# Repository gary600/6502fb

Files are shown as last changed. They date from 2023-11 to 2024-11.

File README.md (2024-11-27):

# 6502 Framebuffer
A 160 by 120 pixel, 256-color framebuffer and VGA generator for a 6502-based computer, made
for CMU 98-341 Build Your Own Breadboard Computer.

Heavily inspired by Ben Eater's "[world's worst video
card](https://www.youtube.com/watch?v=l7rce6IQDWs)" saga, but with many
improvements:
- better timing compliance (shorter critical path -> no vertical artifacts)
- FFs instead of latches (easier to debug timing)
- higher resolution (160x120 vs. 100x75), accomplished through memory banking
- more common VGA mode (640x480 vs. 800x600)
- double-bufferring (updates aren't restricted to blanking period)
- software blanking (show solid black or white without drawing to every pixel)
- configurability (disable NMI if not needed)

This repo contains the KiCad files for the board, a corresponding Verilog
design and testbench, and a software simulator.

The board went through 2 revisions before it worked fully:

## Rev1
Revision 1 worked well enough to generate a valid VGA signal, but I made a major
mistake on the SRAM pinout which led to it not being able to interface with the
6502 computer. Another mistake: my minimum via diameter was too small, so it
cost like $40 extra...

However, despite these faults, I was able to bodge the row and column pins to
allow it to display an image from an EEPROM.

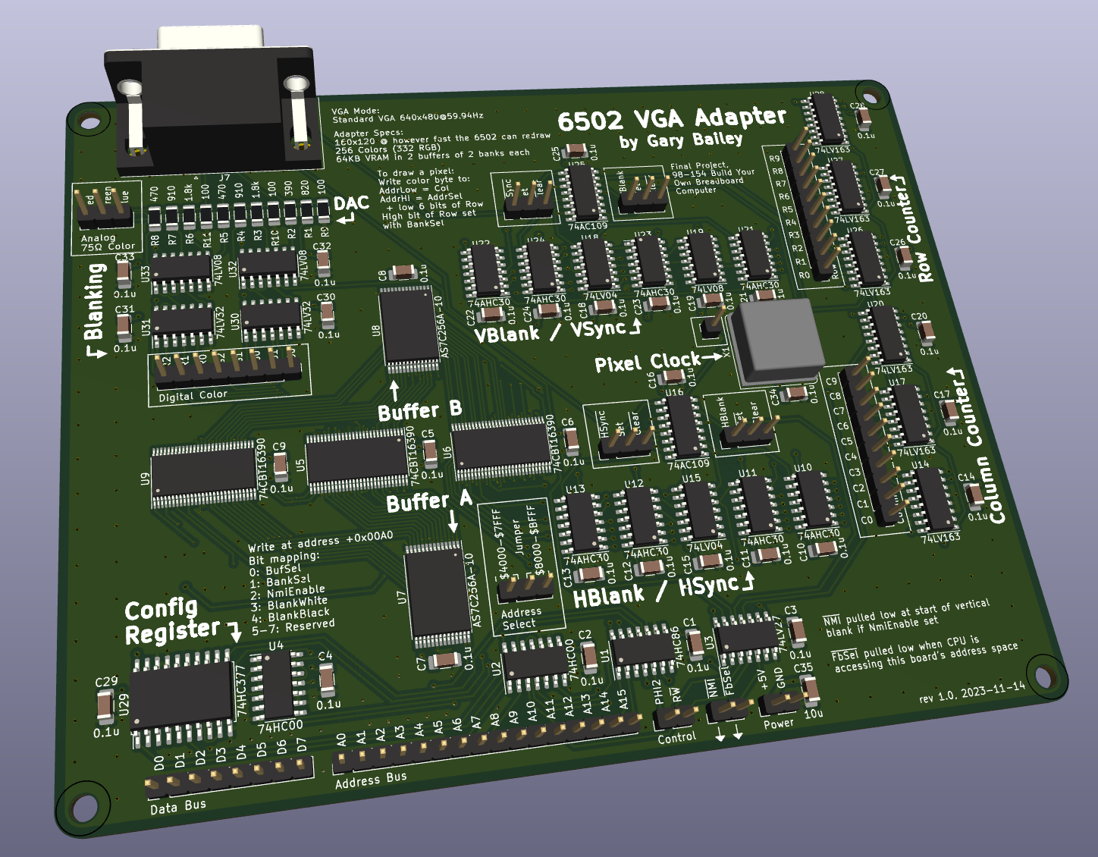
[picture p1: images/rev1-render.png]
KiCad render

KiCad render

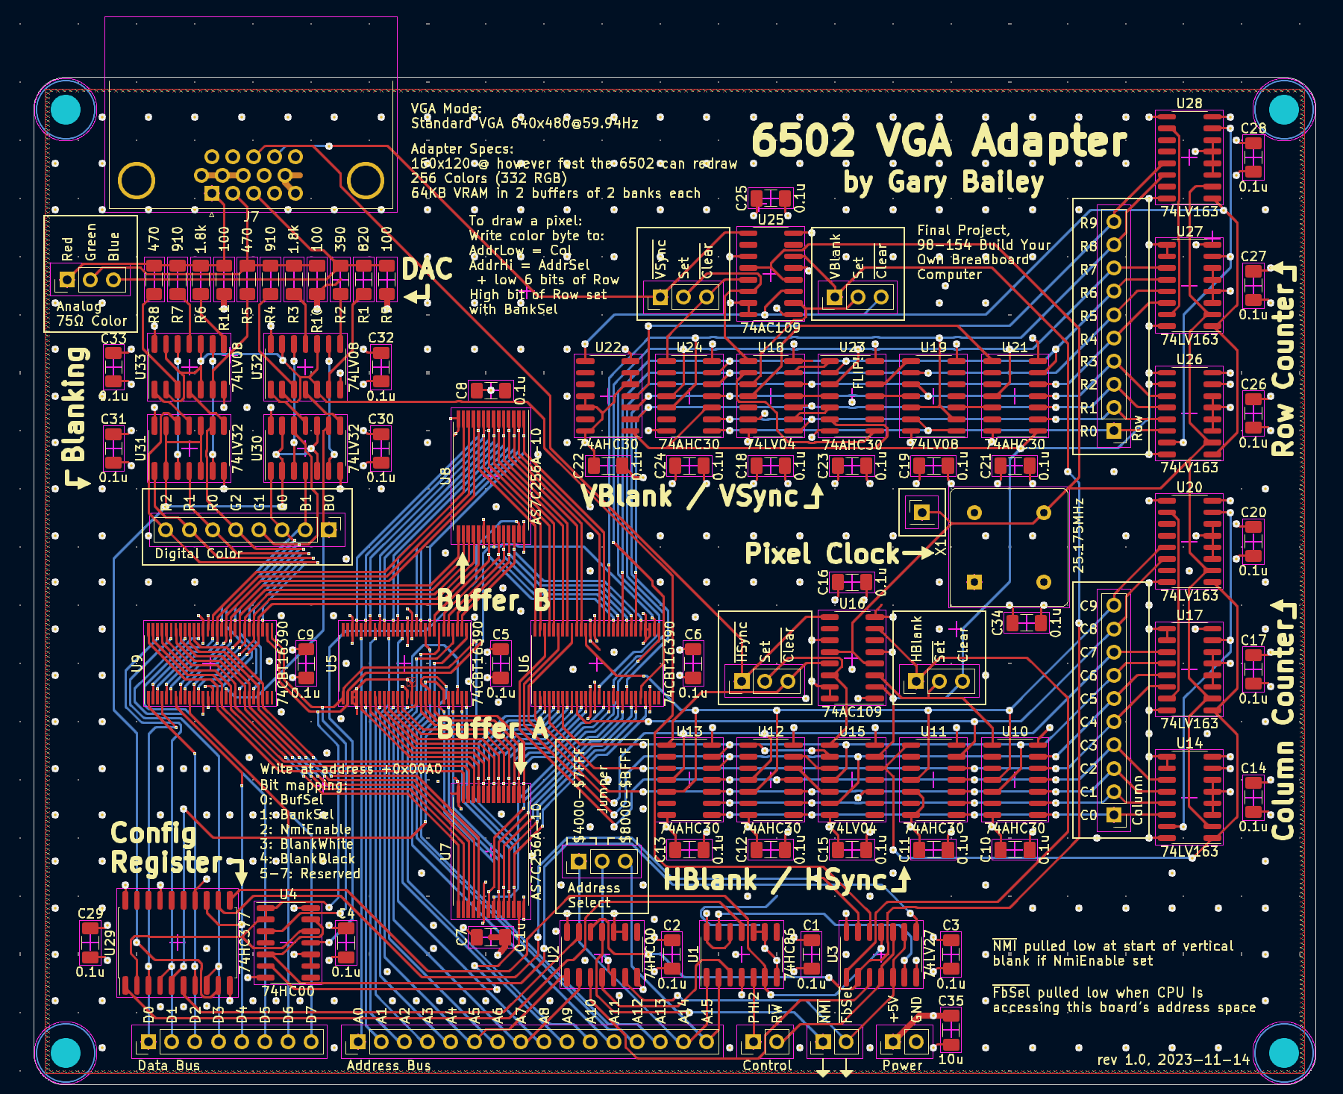
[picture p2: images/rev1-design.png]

KiCad board view

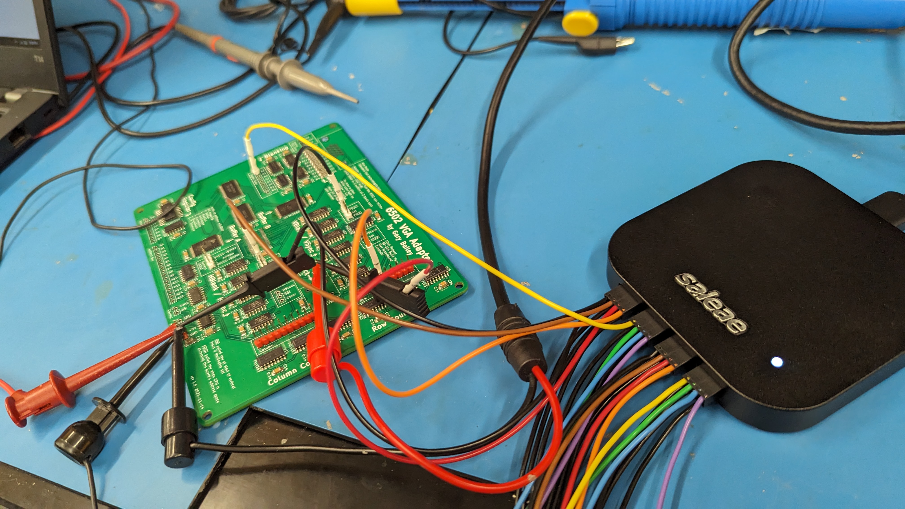
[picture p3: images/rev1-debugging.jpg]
Debugging...
 Part of the arduous debugging
process that eventually led to me discovering the SRAM mistake...

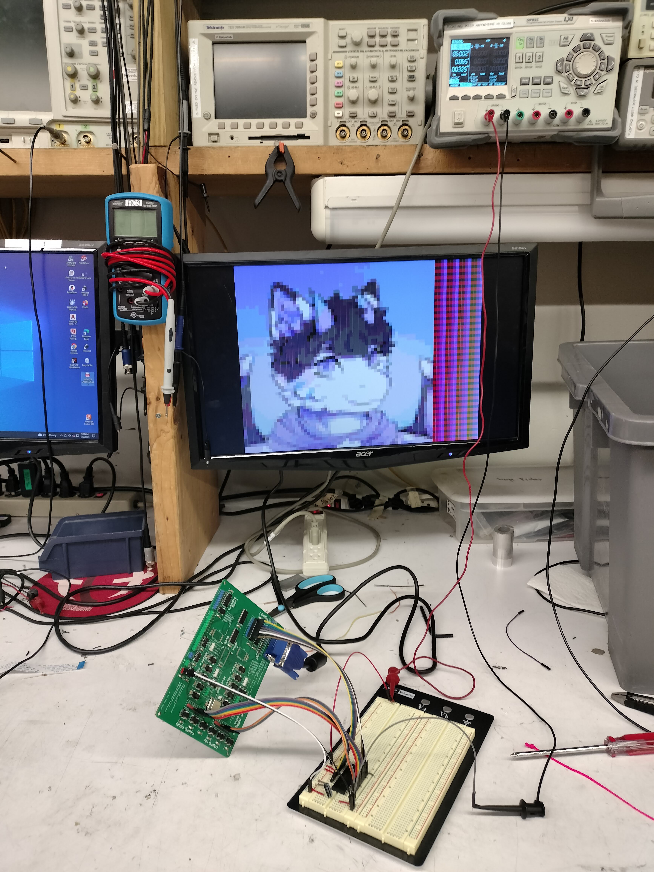
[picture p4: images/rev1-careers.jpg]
It works!
 It works! (with a static image...) The
EEPROM I used here has a much slower read speed than the SRAMs I designed for,
which leads to the vertial artifacts on some pixels here.

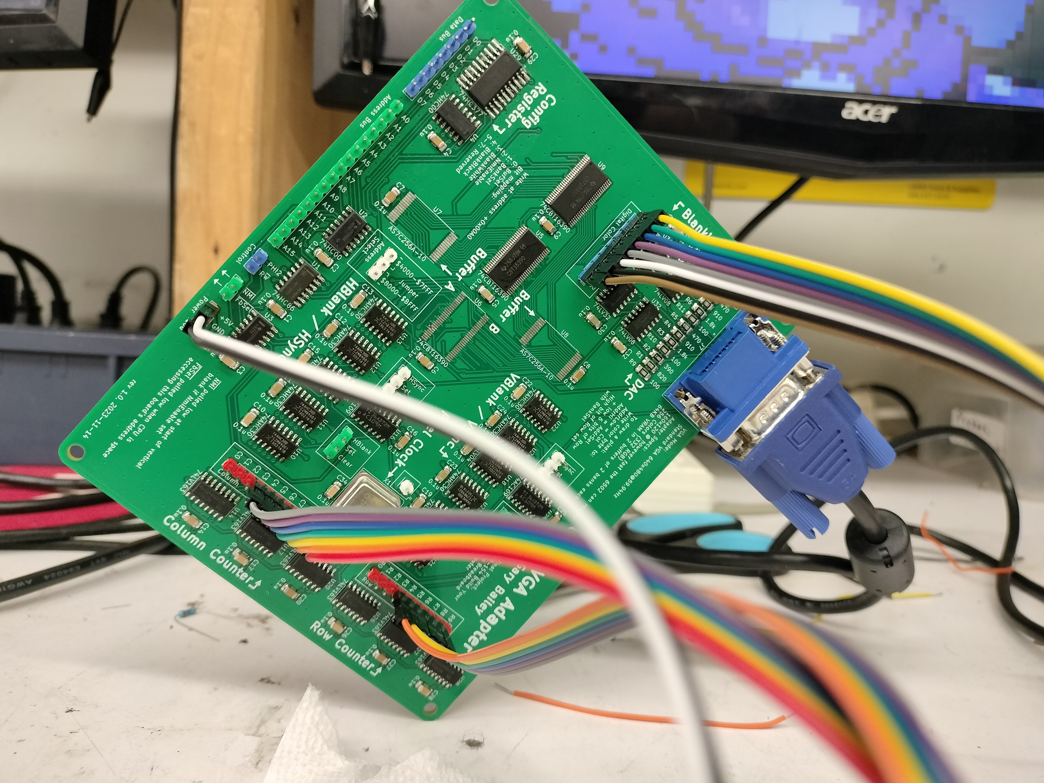
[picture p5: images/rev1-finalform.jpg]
Final form

Closeup of Rev1 bodges: SRAMs removed and row/column signals routed to EEPROM + color routed in through header

## Rev2
Revision 2 fixed the pinout of the SRAM ICs, fixed the via size issue, added a
debug header for the config register, and added an optional 5V regulator that
can be used to power the entire computer.

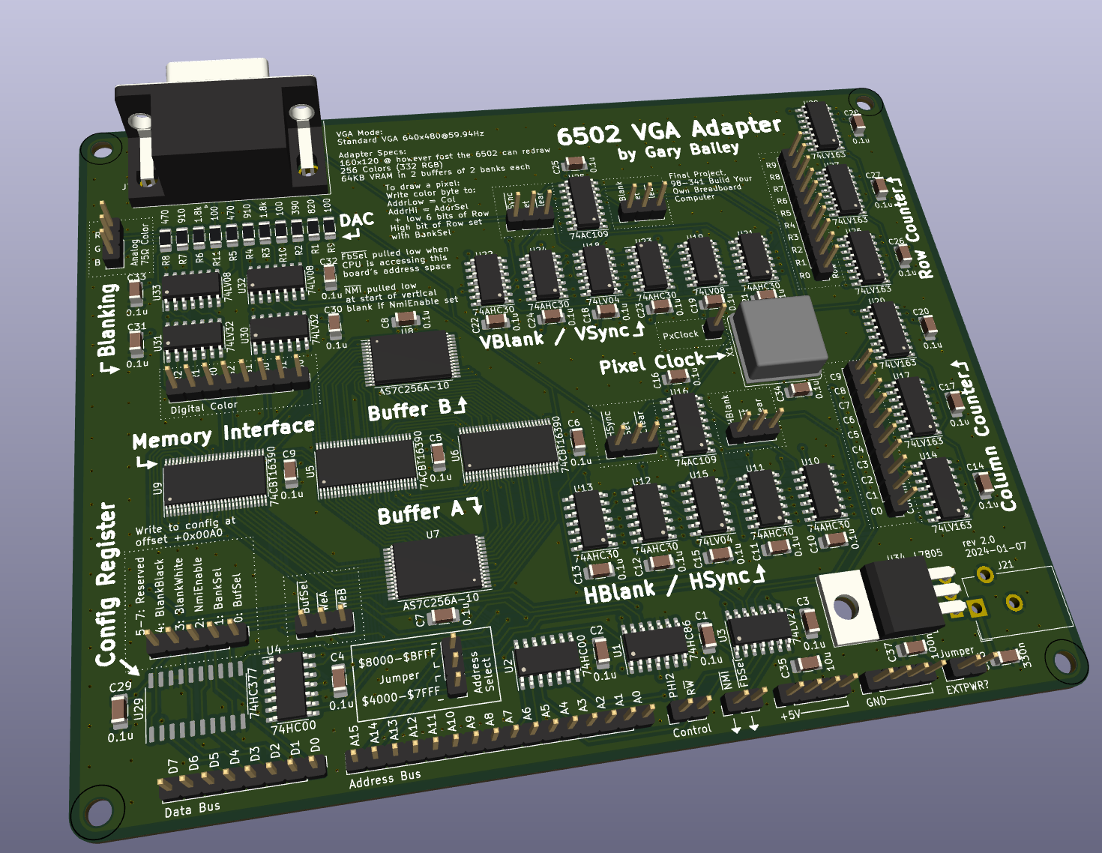
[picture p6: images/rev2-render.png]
KiCad render

KiCad render

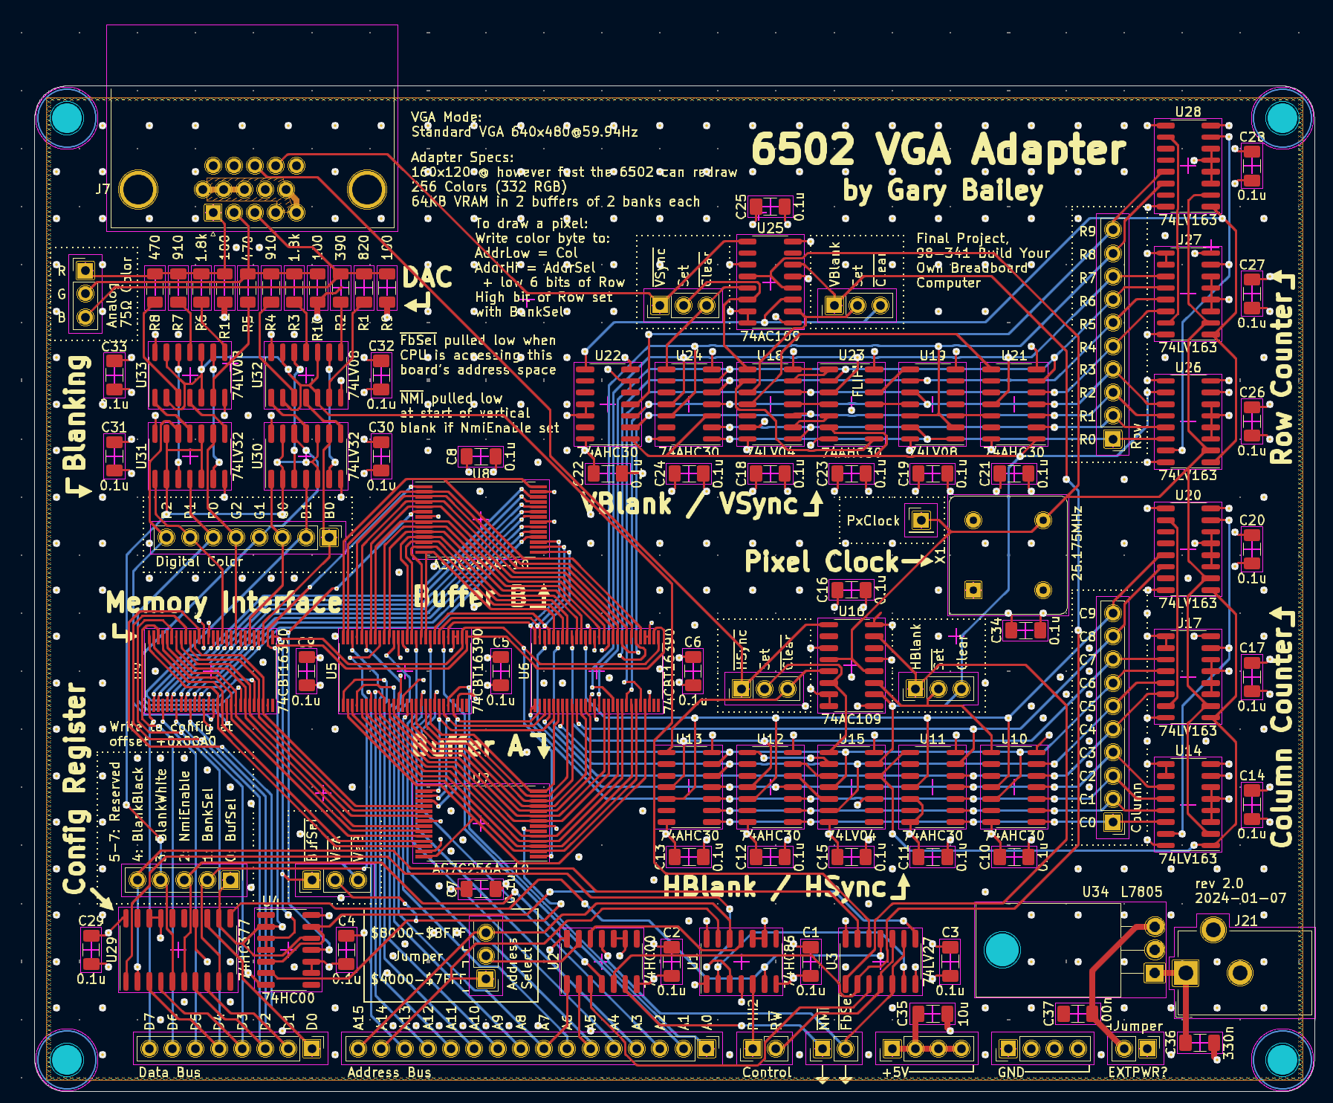
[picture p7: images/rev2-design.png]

KiCad board view

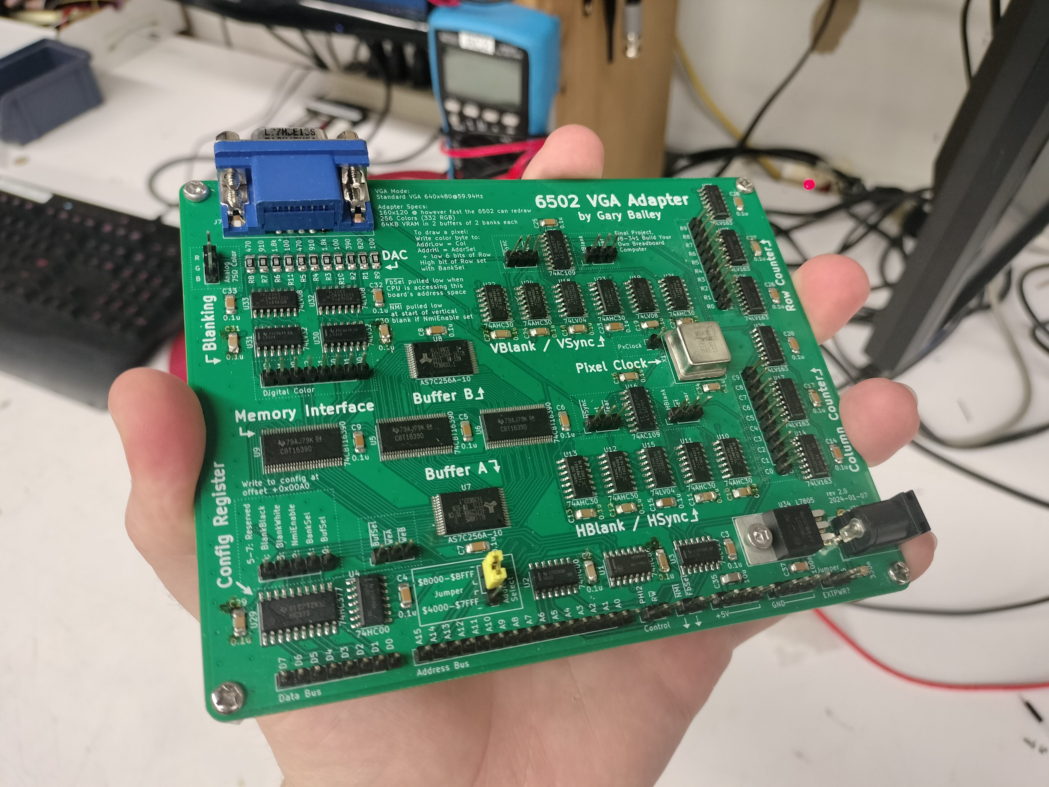
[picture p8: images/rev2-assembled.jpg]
Final assembled board

Final assembled board!

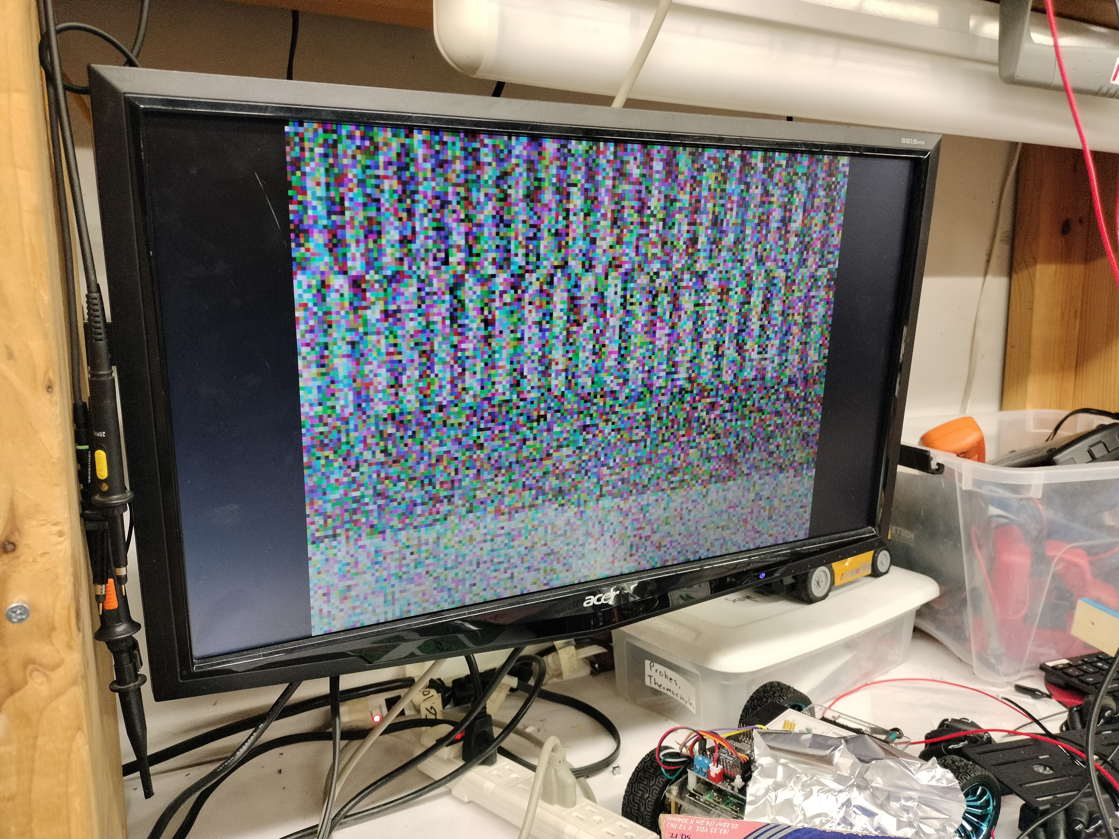
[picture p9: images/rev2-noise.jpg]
Power-on noise

Power-on noise: this is expected! The SRAM does not have a deterministic state when powered on.

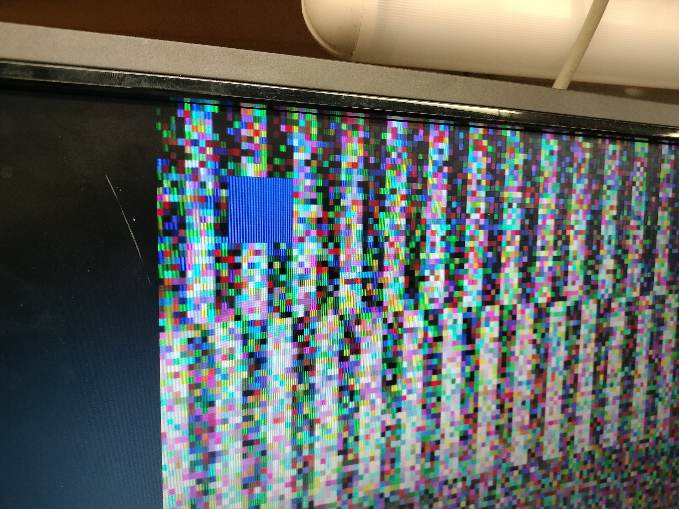
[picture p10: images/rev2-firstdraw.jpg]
Drawing works

Drawing to the screen works!

Moving image
And it can redraw live!

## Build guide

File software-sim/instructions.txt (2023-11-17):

ADC  Add Memory to Accumulator with Carry

     A + M + C -> A, C                N Z C I D V
                                      + + + - - +

     addressing    assembler    opc  bytes  cyles
     --------------------------------------------
     immediate     ADC #oper     69    2     2
     zeropage      ADC oper      65    2     3
     zeropage,X    ADC oper,X    75    2     4
     absolute      ADC oper      6D    3     4
     absolute,X    ADC oper,X    7D    3     4*
     absolute,Y    ADC oper,Y    79    3     4*
     (indirect,X)  ADC (oper,X)  61    2     6
     (indirect),Y  ADC (oper),Y  71    2     5*

AND  AND Memory with Accumulator

     A AND M -> A                     N Z C I D V
                                      + + - - - -

     addressing    assembler    opc  bytes  cyles
     --------------------------------------------
     immediate     AND #oper     29    2     2
     zeropage      AND oper      25    2     3
     zeropage,X    AND oper,X    35    2     4
     absolute      AND oper      2D    3     4
     absolute,X    AND oper,X    3D    3     4*
     absolute,Y    AND oper,Y    39    3     4*
     (indirect,X)  AND (oper,X)  21    2     6
     (indirect),Y  AND (oper),Y  31    2     5*

ASL  Shift Left One Bit (Memory or Accumulator)

     C <- [76543210] <- 0             N Z C I D V
                                      + + + - - -

     addressing    assembler    opc  bytes  cyles
     --------------------------------------------
     accumulator   ASL A         0A    1     2
     zeropage      ASL oper      06    2     5
     zeropage,X    ASL oper,X    16    2     6
     absolute      ASL oper      0E    3     6
     absolute,X    ASL oper,X    1E    3     7

BCC  Branch on Carry Clear

     branch on C = 0                  N Z C I D V
                                      - - - - - -

     addressing    assembler    opc  bytes  cyles
     --------------------------------------------
     relative      BCC oper      90    2     2**

BCS  Branch on Carry Set

     branch on C = 1                  N Z C I D V
                                      - - - - - -

     addressing    assembler    opc  bytes  cyles
     --------------------------------------------
     relative      BCS oper      B0    2     2**

BEQ  Branch on Result Zero

     branch on Z = 1                  N Z C I D V
                                      - - - - - -

     addressing    assembler    opc  bytes  cyles
     --------------------------------------------
     relative      BEQ oper      F0    2     2**

BIT  Test Bits in Memory with Accumulator

     A AND M, M7 -> N, M6 -> V        N Z C I D V
                                     M7 + - - - M6

     addressing    assembler    opc  bytes  cyles
     --------------------------------------------
     zeropage      BIT oper      24    2     3
     absolute      BIT oper      2C    3     4

BMI  Branch on Result Minus

     branch on N = 1                  N Z C I D V
                                      - - - - - -

     addressing    assembler    opc  bytes  cyles
     --------------------------------------------
     relative      BMI oper      30    2     2**

BNE  Branch on Result not Zero

     branch on Z = 0                  N Z C I D V
                                      - - - - - -

     addressing    assembler    opc  bytes  cyles
     --------------------------------------------
     relative      BNE oper      D0    2     2**

BPL  Branch on Result Plus

     branch on N = 0                  N Z C I D V
                                      - - - - - -

     addressing    assembler    opc  bytes  cyles
     --------------------------------------------
     relative      BPL oper      10    2     2**

BRK  Force Break

     interrupt,                       N Z C I D V
     push PC+2, push SR               - - - 1 - -

     addressing    assembler    opc  bytes  cyles
     --------------------------------------------
     implied       BRK           00    1     7

BVC  Branch on Overflow Clear

     branch on V = 0                  N Z C I D V
                                      - - - - - -

     addressing    assembler    opc  bytes  cyles
     --------------------------------------------
     relative      BVC oper      50    2     2**

BVS  Branch on Overflow Set

     branch on V = 1                  N Z C I D V
                                      - - - - - -

     addressing    assembler    opc  bytes  cyles
     --------------------------------------------
     relative      BVC oper      70    2     2**

CLC  Clear Carry Flag

     0 -> C                           N Z C I D V
                                      - - 0 - - -

     addressing    assembler    opc  bytes  cyles
     --------------------------------------------
     implied       CLC           18    1     2

CLD  Clear Decimal Mode

     0 -> D                           N Z C I D V
                                      - - - - 0 -

     addressing    assembler    opc  bytes  cyles
     --------------------------------------------
     implied       CLD           D8    1     2

CLI  Clear Interrupt Disable Bit

     0 -> I                           N Z C I D V
                                      - - - 0 - -

     addressing    assembler    opc  bytes  cyles
     --------------------------------------------
     implied       CLI           58    1     2

CLV  Clear Overflow Flag

     0 -> V                           N Z C I D V
                                      - - - - - 0

     addressing    assembler    opc  bytes  cyles
     --------------------------------------------
     implied       CLV           B8    1     2

CMP  Compare Memory with Accumulator

     A - M                            N Z C I D V
                                    + + + - - -

     addressing    assembler    opc  bytes  cyles
     --------------------------------------------
     immediate     CMP #oper     C9    2     2
     zeropage      CMP oper      C5    2     3
     zeropage,X    CMP oper,X    D5    2     4
     absolute      CMP oper      CD    3     4
     absolute,X    CMP oper,X    DD    3     4*
     absolute,Y    CMP oper,Y    D9    3     4*
     (indirect,X)  CMP (oper,X)  C1    2     6
     (indirect),Y  CMP (oper),Y  D1    2     5*

CPX  Compare Memory and Index X

     X - M                            N Z C I D V
                                      + + + - - -

     addressing    assembler    opc  bytes  cyles
     --------------------------------------------
     immediate     CPX #oper     E0    2     2
     zeropage      CPX oper      E4    2     3
     absolute      CPX oper      EC    3     4

CPY  Compare Memory and Index Y

     Y - M                            N Z C I D V
                                      + + + - - -

     addressing    assembler    opc  bytes  cyles
     --------------------------------------------
     immediate     CPY #oper     C0    2     2
     zeropage      CPY oper      C4    2     3
     absolute      CPY oper      CC    3     4

DEC  Decrement Memory by One

     M - 1 -> M                       N Z C I D V
                                      + + - - - -

     addressing    assembler    opc  bytes  cyles
     --------------------------------------------
     zeropage      DEC oper      C6    2     5
     zeropage,X    DEC oper,X    D6    2     6
     absolute      DEC oper      CE    3     6
     absolute,X    DEC oper,X    DE    3     7

DEX  Decrement Index X by One

     X - 1 -> X                       N Z C I D V
                                      + + - - - -

     addressing    assembler    opc  bytes  cyles
     --------------------------------------------
     implied       DEC           CA    1     2

DEY  Decrement Index Y by One

     Y - 1 -> Y                       N Z C I D V
                                      + + - - - -

     addressing    assembler    opc  bytes  cyles
     --------------------------------------------
     implied       DEC           88    1     2

EOR  Exclusive-OR Memory with Accumulator

     A EOR M -> A                     N Z C I D V
                                      + + - - - -

     addressing    assembler    opc  bytes  cyles
     --------------------------------------------
     immediate     EOR #oper     49    2     2
     zeropage      EOR oper      45    2     3
     zeropage,X    EOR oper,X    55    2     4
     absolute      EOR oper      4D    3     4
     absolute,X    EOR oper,X    5D    3     4*
     absolute,Y    EOR oper,Y    59    3     4*
     (indirect,X)  EOR (oper,X)  41    2     6
     (indirect),Y  EOR (oper),Y  51    2     5*

INC  Increment Memory by One

     M + 1 -> M                       N Z C I D V
                                      + + - - - -

     addressing    assembler    opc  bytes  cyles
     --------------------------------------------
     zeropage      INC oper      E6    2     5
     zeropage,X    INC oper,X    F6    2     6
     absolute      INC oper      EE    3     6
     absolute,X    INC oper,X    FE    3     7

INX  Increment Index X by One

     X + 1 -> X                       N Z C I D V
                                      + + - - - -

     addressing    assembler    opc  bytes  cyles
     --------------------------------------------
     implied       INX           E8    1     2

INY  Increment Index Y by One

     Y + 1 -> Y                       N Z C I D V
                                      + + - - - -

     addressing    assembler    opc  bytes  cyles
     --------------------------------------------
     implied       INY           C8    1     2

JMP  Jump to New Location

     (PC+1) -> PCL                    N Z C I D V
     (PC+2) -> PCH                    - - - - - -

     addressing    assembler    opc  bytes  cyles
     --------------------------------------------
     absolute      JMP oper      4C    3     3
     indirect      JMP (oper)    6C    3     5

JSR  Jump to New Location Saving Return Address

     push (PC+2),                     N Z C I D V
     (PC+1) -> PCL                    - - - - - -

     addressing    assembler    opc  bytes  cyles
     --------------------------------------------
     absolute      JSR oper      20    3     6

LDA  Load Accumulator with Memory

     M -> A                           N Z C I D V
                                      + + - - - -

     addressing    assembler    opc  bytes  cyles
     --------------------------------------------
     immediate     LDA #oper     A9    2     2
     zeropage      LDA oper      A5    2     3
     zeropage,X    LDA oper,X    B5    2     4
     absolute      LDA oper      AD    3     4
     absolute,X    LDA oper,X    BD    3     4*
     absolute,Y    LDA oper,Y    B9    3     4*
     (indirect,X)  LDA (oper,X)  A1    2     6
     (indirect),Y  LDA (oper),Y  B1    2     5*

LDX  Load Index X with Memory

     M -> X                           N Z C I D V
                                      + + - - - -

     addressing    assembler    opc  bytes  cyles
     --------------------------------------------
     immediate     LDX #oper     A2    2     2
     zeropage      LDX oper      A6    2     3
     zeropage,Y    LDX oper,Y    B6    2     4
     absolute      LDX oper      AE    3     4
     absolute,Y    LDX oper,Y    BE    3     4*

LDY  Load Index Y with Memory

     M -> Y                           N Z C I D V
                                      + + - - - -

     addressing    assembler    opc  bytes  cyles
     --------------------------------------------
     immediate     LDY #oper     A0    2     2
     zeropage      LDY oper      A4    2     3
     zeropage,X    LDY oper,X    B4    2     4
     absolute      LDY oper      AC    3     4
     absolute,X    LDY oper,X    BC    3     4*

LSR  Shift One Bit Right (Memory or Accumulator)

     0 -> [76543210] -> C             N Z C I D V
                                      0 + + - - -

     addressing    assembler    opc  bytes  cyles
     --------------------------------------------
     accumulator   LSR A         4A    1     2
     zeropage      LSR oper      46    2     5
     zeropage,X    LSR oper,X    56    2     6
     absolute      LSR oper      4E    3     6
     absolute,X    LSR oper,X    5E    3     7

NOP  No Operation

     ---                              N Z C I D V
                                      - - - - - -

     addressing    assembler    opc  bytes  cyles
     --------------------------------------------
     implied       NOP           EA    1     2

ORA  OR Memory with Accumulator

     A OR M -> A                      N Z C I D V
                                      + + - - - -

     addressing    assembler    opc  bytes  cyles
     --------------------------------------------
     immediate     ORA #oper     09    2     2
     zeropage      ORA oper      05    2     3
     zeropage,X    ORA oper,X    15    2     4
     absolute      ORA oper      0D    3     4
     absolute,X    ORA oper,X    1D    3     4*
     absolute,Y    ORA oper,Y    19    3     4*
     (indirect,X)  ORA (oper,X)  01    2     6
     (indirect),Y  ORA (oper),Y  11    2     5*

PHA  Push Accumulator on Stack

     push A                           N Z C I D V
                                      - - - - - -

     addressing    assembler    opc  bytes  cyles
     --------------------------------------------
     implied       PHA           48    1     3

PHP  Push Processor Status on Stack

     push SR                          N Z C I D V
                                      - - - - - -

     addressing    assembler    opc  bytes  cyles
     --------------------------------------------
     implied       PHP           08    1     3

PLA  Pull Accumulator from Stack

     pull A                           N Z C I D V
                                      + + - - - -

     addressing    assembler    opc  bytes  cyles
     --------------------------------------------
     implied       PLA           68    1     4

PLP  Pull Processor Status from Stack

     pull SR                          N Z C I D V
                                      from stack

     addressing    assembler    opc  bytes  cyles
     --------------------------------------------
     implied       PLP           28    1     4

ROL  Rotate One Bit Left (Memory or Accumulator)

     C <- [76543210] <- C             N Z C I D V
                                      + + + - - -

     addressing    assembler    opc  bytes  cyles
     --------------------------------------------
     accumulator   ROL A         2A    1     2
     zeropage      ROL oper      26    2     5
     zeropage,X    ROL oper,X    36    2     6
     absolute      ROL oper      2E    3     6
     absolute,X    ROL oper,X    3E    3     7

ROR  Rotate One Bit Right (Memory or Accumulator)

     C -> [76543210] -> C             N Z C I D V
                                      + + + - - -

     addressing    assembler    opc  bytes  cyles
     --------------------------------------------
     accumulator   ROR A         6A    1     2
     zeropage      ROR oper      66    2     5
     zeropage,X    ROR oper,X    76    2     6
     absolute      ROR oper      6E    3     6
     absolute,X    ROR oper,X    7E    3     7

RTI  Return from Interrupt

     pull SR, pull PC                 N Z C I D V
                                      from stack

     addressing    assembler    opc  bytes  cyles
     --------------------------------------------
     implied       RTI           40    1     6

RTS  Return from Subroutine

     pull PC, PC+1 -> PC              N Z C I D V
                                      - - - - - -

     addressing    assembler    opc  bytes  cyles
     --------------------------------------------
     implied       RTS           60    1     6

SBC  Subtract Memory from Accumulator with Borrow

     A - M - C -> A                   N Z C I D V
                                      + + + - - +

     addressing    assembler    opc  bytes  cyles
     --------------------------------------------
     immediate     SBC #oper     E9    2     2
     zeropage      SBC oper      E5    2     3
     zeropage,X    SBC oper,X    F5    2     4
     absolute      SBC oper      ED    3     4
     absolute,X    SBC oper,X    FD    3     4*
     absolute,Y    SBC oper,Y    F9    3     4*
     (indirect,X)  SBC (oper,X)  E1    2     6
     (indirect),Y  SBC (oper),Y  F1    2     5*

SEC  Set Carry Flag

     1 -> C                           N Z C I D V
                                      - - 1 - - -

     addressing    assembler    opc  bytes  cyles
     --------------------------------------------
     implied       SEC           38    1     2

SED  Set Decimal Flag

     1 -> D                           N Z C I D V
                                      - - - - 1 -

     addressing    assembler    opc  bytes  cyles
     --------------------------------------------
     implied       SED           F8    1     2

SEI  Set Interrupt Disable Status

     1 -> I                           N Z C I D V
                                      - - - 1 - -

     addressing    assembler    opc  bytes  cyles
     --------------------------------------------
     implied       SEI           78    1     2

STA  Store Accumulator in Memory

     A -> M                           N Z C I D V
                                      - - - - - -

     addressing    assembler    opc  bytes  cyles
     --------------------------------------------
     zeropage      STA oper      85    2     3
     zeropage,X    STA oper,X    95    2     4
     absolute      STA oper      8D    3     4
     absolute,X    STA oper,X    9D    3     5
     absolute,Y    STA oper,Y    99    3     5
     (indirect,X)  STA (oper,X)  81    2     6
     (indirect),Y  STA (oper),Y  91    2     6

STX  Store Index X in Memory

     X -> M                           N Z C I D V
                                      - - - - - -

     addressing    assembler    opc  bytes  cyles
     --------------------------------------------
     zeropage      STX oper      86    2     3
     zeropage,Y    STX oper,Y    96    2     4
     absolute      STX oper      8E    3     4

STY  Sore Index Y in Memory

     Y -> M                           N Z C I D V
                                      - - - - - -

     addressing    assembler    opc  bytes  cyles
     --------------------------------------------
     zeropage      STY oper      84    2     3
     zeropage,X    STY oper,X    94    2     4
     absolute      STY oper      8C    3     4

TAX  Transfer Accumulator to Index X

     A -> X                           N Z C I D V
                                      + + - - - -

     addressing    assembler    opc  bytes  cyles
     --------------------------------------------
     implied       TAX           AA    1     2

TAY  Transfer Accumulator to Index Y

     A -> Y                           N Z C I D V
                                      + + - - - -

     addressing    assembler    opc  bytes  cyles
     --------------------------------------------
     implied       TAY           A8    1     2

TSX  Transfer Stack Pointer to Index X

     SP -> X                          N Z C I D V
                                      + + - - - -

     addressing    assembler    opc  bytes  cyles
     --------------------------------------------
     implied       TSX           BA    1     2

TXA  Transfer Index X to Accumulator

     X -> A                           N Z C I D V
                                      + + - - - -

     addressing    assembler    opc  bytes  cyles
     --------------------------------------------
     implied       TXA           8A    1     2

TXS  Transfer Index X to Stack Register

     X -> SP                          N Z C I D V
                                      - - - - - -

     addressing    assembler    opc  bytes  cyles
     --------------------------------------------
     implied       TXS           9A    1     2

TYA  Transfer Index Y to Accumulator

     Y -> A                           N Z C I D V
                                      + + - - - -

     addressing    assembler    opc  bytes  cyles
     --------------------------------------------
     implied       TYA           98    1     2

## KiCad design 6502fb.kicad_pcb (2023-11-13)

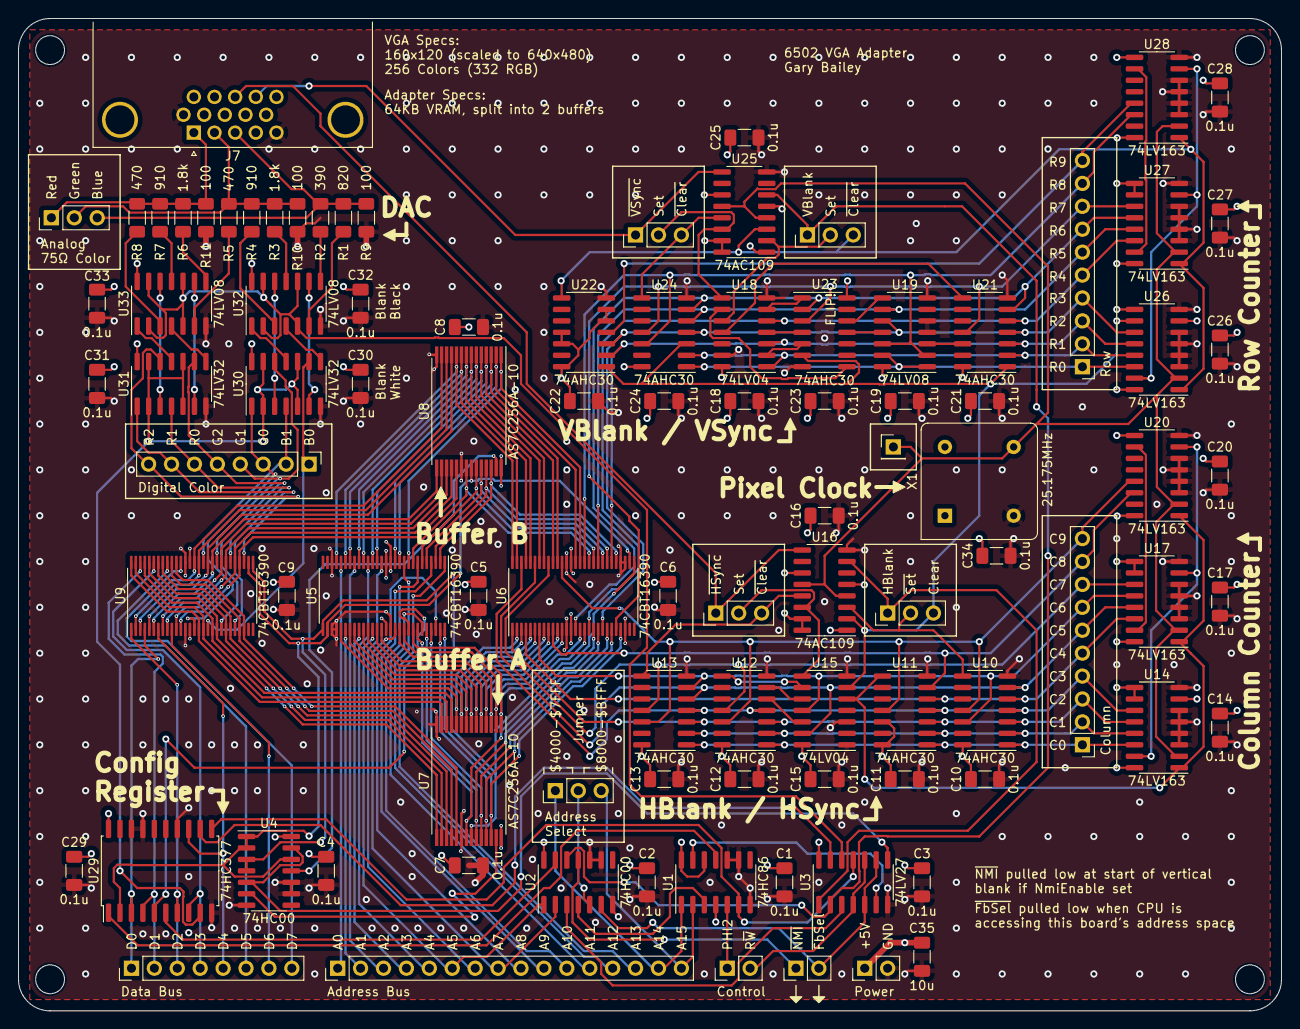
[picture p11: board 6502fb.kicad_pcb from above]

Board: 4 copper layers, 140.0 x 110.0 mm, 100 parts (0 on the bottom side), 168 nets.

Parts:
C1, C2, C3, C4, C5, C6, C7, C8, C9, C10, C11, C12, C13, C14, C15, C16, C17, C18, C19, C20, C21, C22, C23, C24, C25, C26, C27, C28, C29, C30, C31, C32, C33, C34: 0.1u; C_1206_3216Metric_Pad1.33x1.80mm_HandSolder
C35: 10u; C_1206_3216Metric_Pad1.33x1.80mm_HandSolder
H1, H2, H3, H4: MountingHole; MountingHole_3.2mm_M3
J1, J3, J5: Conn_01x02; PinHeader_1x02_P2.54mm_Vertical
J2, J8: Conn_01x08; PinHeader_1x08_P2.54mm_Vertical
J4: Conn_01x16; PinHeader_1x16_P2.54mm_Vertical
J6, J11, J12, J13, J14, J15: Conn_01x03; PinHeader_1x03_P2.54mm_Vertical
J7: DE15_Receptacle_HighDensity; DSUB-15-HD_Female_Horizontal_P2.29x1.98mm_EdgePinOffset8.35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
J9, J10: Conn_01x10; PinHeader_1x10_P2.54mm_Vertical
J16: Conn_01x01; PinHeader_1x01_P2.54mm_Vertical
R1: 820; R_1206_3216Metric_Pad1.30x1.75mm_HandSolder
R2: 390; R_1206_3216Metric_Pad1.30x1.75mm_HandSolder
R3, R6: 1.8k; R_1206_3216Metric_Pad1.30x1.75mm_HandSolder
R4, R7: 910; R_1206_3216Metric_Pad1.30x1.75mm_HandSolder
R5, R8: 470; R_1206_3216Metric_Pad1.30x1.75mm_HandSolder
R9, R10, R11: 100; R_1206_3216Metric_Pad1.30x1.75mm_HandSolder
U1: 74HC86; SOIC-14_3.9x8.7mm_P1.27mm
U2, U4: 74HC00; SOIC-14_3.9x8.7mm_P1.27mm
U3: 74LV27; SOIC-14_3.9x8.7mm_P1.27mm
U5, U6, U9: 74CBT16390; TSSOP-56_6.1x14mm_P0.5mm
U7, U8: AS7C256A-10; TSOP-I-28_11.8x8mm_P0.55mm
U10, U11, U12, U13, U21, U22, U23, U24: 74AHC30; SOIC-14_3.9x8.7mm_P1.27mm
U14, U17, U20, U26, U27, U28: 74LV163; SOIC-16_3.9x9.9mm_P1.27mm
U15, U18: 74LV04; SOIC-14_3.9x8.7mm_P1.27mm
U16, U25: 74AC109; SOIC-16_3.9x9.9mm_P1.27mm
U19, U32, U33: 74LV08; SOIC-14_3.9x8.7mm_P1.27mm
U29: 74HC377; SOIC-20W_7.5x12.8mm_P1.27mm
U30, U31: 74LV32; SOIC-14_3.9x8.7mm_P1.27mm
X1: 25.175MHz; Oscillator_DIP-8

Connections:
+5V: C1.1, C2.1, C3.1, C4.1, C5.1, C6.1, C7.1, C8.1, C9.1, C10.1, C11.1, C12.1, C13.1, C14.1, C15.1, C16.1, C17.1, C18.1, C19.1, C20.1, C21.1, C22.1, C23.1, C24.1, C25.1, C26.1, C27.1, C28.1, C29.1, C30.1, C31.1, C32.1, C33.1, C34.1, C35.1, J3.1, U1.4, U1.12, U1.14 (VCC), U2.14 (VCC), U3.14 (VCC), U4.14 (VCC), U5.14 (V_{CC}), U5.43 (V_{CC}), U6.14 (V_{CC}), U6.43 (V_{CC}), U7.28 (VCC), U8.28 (VCC), U9.14 (V_{CC}), U9.43 (V_{CC}), U10.14 (VCC), U11.12, U11.14 (VCC), U12.14 (VCC), U13.14 (VCC), U14.7 (CEP), U14.9 (~PE), U14.10 (CET), U14.16 (VCC), U15.14 (VCC), U16.1 (~R), U16.5 (~S), U16.11 (~S), U16.15 (~R), U16.16 (VCC), U17.9 (~PE), U17.10 (CET), U17.16 (VCC), U18.14 (VCC), U19.14 (VCC), U20.9 (~PE), U20.16 (VCC), U21.14 (VCC), U22.5, U22.6, U22.11, U22.12, U22.14 (VCC), U23.14 (VCC), U24.14 (VCC), U25.1 (~R), U25.5 (~S), U25.11 (~S), U25.15 (~R), U25.16 (VCC), U26.7 (CEP), U26.9 (~PE), U26.16 (VCC), U27.9 (~PE), U27.10 (CET), U27.16 (VCC), U28.9 (~PE), U28.16 (VCC), U29.20 (VCC), U30.14 (VCC), U31.14 (VCC), U32.14 (VCC), U33.14 (VCC), X1.1 (EN), X1.8 (Vcc)
/AddrPhys14: J4.15, J6.1, U1.1
/AddrPhys15: J4.16, J6.3, U1.2
/AddrSel: J6.2, U2.5
/Blue: J7.3, J15.3, R1.2, R2.2, R9.1
/ConfigReg/BlankBlack: U3.13, U29.12 (Q4)
/ConfigReg/BlankWhite: U29.9 (Q3), U30.2, U30.5, U30.10, U30.13, U31.2, U31.5, U31.10, U31.13
/ConfigReg/DataIn0: J2.1, U9.4 (A3), U29.3 (D0)
/ConfigReg/DataIn1: J2.2, U9.54 (A2), U29.4 (D1)
/ConfigReg/DataIn2: J2.3, U9.1 (A1), U29.7 (D2)
/ConfigReg/DataIn3: J2.4, U9.51 (A4), U29.8 (D3)
/ConfigReg/DataIn4: J2.5, U9.7 (A5), U29.13 (D4)
/ConfigReg/DataIn5: J2.6, U9.48 (A6)
/ConfigReg/DataIn6: J2.7, U9.10 (A7)
/ConfigReg/DataIn7: J2.8, U9.45 (A8)
/ConfigReg/NmiEnable: U2.13, U29.6 (Q2)
/Counters/Col0: J10.1, U10.1, U11.1, U12.1, U13.1, U14.14 (Q0)
/Counters/Col1: J10.2, U10.2, U11.2, U12.2, U13.2, U14.13 (Q1)
/Counters/Col2: J10.3, U6.1 (A1), U10.3, U11.3, U12.3, U13.3, U14.12 (Q2)
/Counters/Col3: J10.4, U6.54 (A2), U10.4, U11.4, U12.4, U13.4, U14.11 (Q3)
/Counters/Col4: J10.5, U6.4 (A3), U10.5, U11.5, U17.14 (Q0)
/Counters/Col5: J10.6, U6.51 (A4), U10.6, U13.5, U15.13, U17.13 (Q1)
/Counters/Col6: J10.7, U6.7 (A5), U10.12, U13.6, U15.11, U17.12 (Q2)
/Counters/Col7: J10.8, U6.48 (A6), U12.11, U13.11, U17.11 (Q3)
/Counters/Col8: J10.9, U6.10 (A7), U11.6, U20.14 (Q0)
/Counters/Col9: J10.10, U6.45 (A8), U10.11, U11.11, U12.12, U13.12, U20.13 (Q1)
/Counters/HBlankClear: J11.3, U15.6, U16.2 (J), U21.1, U22.1, U23.6, U24.3, U26.10 (CET)
/Counters/HSyncSet: J12.2, U15.8, U16.14 (J)
/Counters/PxClock: J16.1, U14.2 (CP), U16.4 (C), U16.12 (C), U17.2 (CP), U20.2 (CP), U25.4 (C), U25.12 (C), U26.2 (CP), U27.2 (CP), U28.2 (CP), X1.5 (OUT)
/Counters/Row0: J9.1, U19.1, U19.13, U24.1, U26.14 (Q0)
/Counters/Row1: J9.2, U18.1, U21.2, U24.2, U26.13 (Q1)
/Counters/Row2: J9.3, U6.34 (A14), U18.3, U21.3, U22.2, U26.12 (Q2)
/Counters/Row3: J9.4, U6.21 (A13), U19.10, U21.4, U22.3, U24.4, U26.11 (Q3)
/Counters/Row4: J9.5, U6.18 (A11), U18.5, U21.5, U27.14 (Q0)
/Counters/Row5: J9.6, U6.37 (A12), U19.9, U24.5, U27.13 (Q1)
/Counters/Row6: J9.7, U6.15 (A9), U21.6, U23.2, U24.6, U27.12 (Q2)
/Counters/Row7: J9.8, U6.24 (A15), U21.11, U23.3, U24.11, U27.11 (Q3)
/Counters/Row8: J9.9, U6.40 (A10), U19.2, U19.12, U24.12, U28.14 (Q0)
/Counters/Row9: J9.10, U22.4, U28.13 (Q1)
/Counters/VBlankSet: J13.2, U18.10, U25.2 (J)
/Counters/VSyncSet: J14.2, U18.8, U25.14 (J)
/Counters/~Col5: U12.5, U15.12
/Counters/~Col6: U12.6, U15.10
/Counters/~HBlankClear: U11.8, U14.1 (~MR), U15.5, U17.1 (~MR), U20.1 (~MR)
/Counters/~HBlankSet: J11.2, U10.8, U16.3 (~K)
/Counters/~HSyncClear: J12.3, U13.8, U16.13 (~K)
/Counters/~Row1: U18.2, U23.5
/Counters/~Row2: U18.4, U23.4
/Counters/~Row4: U18.6, U23.1
/Counters/~VBlankClear: J13.3, U22.8, U25.3 (~K), U26.1 (~MR), U27.1 (~MR), U28.1 (~MR)
/Counters/~VSyncClear: J14.3, U24.8, U25.13 (~K)
/DAC/PixelOut0: J8.1, U9.18 (A11), U30.9
/DAC/PixelOut1: J8.2, U9.40 (A10), U30.4
/DAC/PixelOut2: J8.3, U9.15 (A9), U30.1
/DAC/PixelOut3: J8.4, U9.37 (A12), U30.12
/DAC/PixelOut4: J8.5, U9.21 (A13), U31.9
/DAC/PixelOut5: J8.6, U9.34 (A14), U31.4
/DAC/PixelOut6: J8.7, U9.24 (A15), U31.1
/DAC/PixelOut7: J8.8, U9.31 (A16), U31.12
/DAC/~BlankBlack: U3.12, U32.2, U32.5, U32.10, U32.13, U33.2, U33.5, U33.10, U33.13
/Green: J7.2, J15.2, R3.2, R4.2, R5.2, R10.1
/HBlank: J11.1, U3.1, U16.7 (~Q)
/Memory/AddrA0: U5.33 (1B15), U6.2 (2B1), U7.10 (A0)
/Memory/AddrA1: U5.35 (1B14), U6.3 (2B2), U7.9 (A1)
/Memory/AddrA2: U5.36 (1B13), U6.5 (2B3), U7.8 (A2)
/Memory/AddrA3: U5.38 (1B12), U6.6 (2B4), U7.7 (A3)
/Memory/AddrA4: U5.39 (1B11), U6.8 (2B5), U7.6 (A4)
/Memory/AddrA5: U5.41 (1B10), U6.9 (2B6), U7.5 (A5)
/Memory/AddrA6: U5.42 (1B9), U6.11 (2B7), U7.4 (A6)
/Memory/AddrA7: U5.46 (1B8), U6.12 (2B8), U7.3 (A7)
/Memory/AddrA8: U5.55 (1B2), U6.23 (2B14), U7.25 (A8)
/Memory/AddrA9: U5.53 (1B3), U6.22 (2B13), U7.24 (A9)
/Memory/AddrA10: U5.50 (1B5), U6.19 (2B11), U7.21 (A10)
/Memory/AddrA11: U5.52 (1B4), U6.20 (2B12), U7.23 (A11)
/Memory/AddrA12: U5.47 (1B7), U6.16 (2B9), U7.2 (A12)
/Memory/AddrA13: U5.56 (1B1), U6.25 (2B15), U7.26 (A13)
/Memory/AddrA14: U5.49 (1B6), U6.17 (2B10), U7.1 (A14)
/Memory/AddrB0: U5.25 (2B15), U6.56 (1B1), U8.10 (A0)
/Memory/AddrB1: U5.23 (2B14), U6.55 (1B2), U8.9 (A1)
/Memory/AddrB2: U5.22 (2B13), U6.53 (1B3), U8.8 (A2)
/Memory/AddrB3: U5.20 (2B12), U6.52 (1B4), U8.7 (A3)
/Memory/AddrB4: U5.19 (2B11), U6.50 (1B5), U8.6 (A4)
/Memory/AddrB5: U5.17 (2B10), U6.49 (1B6), U8.5 (A5)
/Memory/AddrB6: U5.16 (2B9), U6.47 (1B7), U8.4 (A6)
/Memory/AddrB7: U5.12 (2B8), U6.46 (1B8), U8.3 (A7)
/Memory/AddrB8: U5.3 (2B2), U6.35 (1B14), U8.25 (A8)
/Memory/AddrB9: U5.5 (2B3), U6.36 (1B13), U8.24 (A9)
/Memory/AddrB10: U5.8 (2B5), U6.39 (1B11), U8.21 (A10)
/Memory/AddrB11: U5.6 (2B4), U6.38 (1B12), U8.23 (A11)
/Memory/AddrB12: U5.11 (2B7), U6.42 (1B9), U8.2 (A12)
/Memory/AddrB13: U5.2 (2B1), U6.33 (1B15), U8.26 (A13)
/Memory/AddrB14: U5.9 (2B6), U6.41 (1B10), U8.1 (A14)
/Memory/AddrCPU0: J4.1, U5.24 (A15)
/Memory/AddrCPU1: J4.2, U5.34 (A14)
/Memory/AddrCPU2: J4.3, U5.21 (A13)
/Memory/AddrCPU3: J4.4, U5.37 (A12)
/Memory/AddrCPU4: J4.5, U5.18 (A11)
/Memory/AddrCPU5: J4.6, U2.1, U5.40 (A10)
/Memory/AddrCPU6: J4.7, U5.15 (A9)
/Memory/AddrCPU7: J4.8, U2.2, U5.45 (A8)
/Memory/AddrCPU8: J4.9, U5.54 (A2)
/Memory/AddrCPU9: J4.10, U5.4 (A3)
/Memory/AddrCPU10: J4.11, U5.7 (A5)
/Memory/AddrCPU11: J4.12, U5.51 (A4)
/Memory/AddrCPU12: J4.13, U5.10 (A7)
/Memory/AddrCPU13: J4.14, U5.1 (A1)
/Memory/AddrCPU14: U5.48 (A6), U29.5 (Q1)
/Memory/BufSel: U4.1, U4.2, U4.12, U5.30 (~OE1), U6.30 (~OE1), U8.22 (~OE), U9.30 (~OE1), U29.2 (Q0)
/Memory/DataA0: U7.11 (Q0), U9.19 (2B11), U9.53 (1B3)
/Memory/DataA1: U7.12 (Q1), U9.17 (2B10), U9.55 (1B2)
/Memory/DataA2: U7.13 (Q2), U9.16 (2B9), U9.56 (1B1)
/Memory/DataA3: U7.15 (Q3), U9.20 (2B12), U9.52 (1B4)
/Memory/DataA4: U7.16 (Q4), U9.22 (2B13), U9.50 (1B5)
/Memory/DataA5: U7.17 (Q5), U9.23 (2B14), U9.49 (1B6)
/Memory/DataA6: U7.18 (Q6), U9.25 (2B15), U9.47 (1B7)
/Memory/DataA7: U7.19 (Q7), U9.26 (2B16), U9.46 (1B8)
/Memory/DataB0: U8.11 (Q0), U9.5 (2B3), U9.39 (1B11)
/Memory/DataB1: U8.12 (Q1), U9.3 (2B2), U9.41 (1B10)
/Memory/DataB2: U8.13 (Q2), U9.2 (2B1), U9.42 (1B9)
/Memory/DataB3: U8.15 (Q3), U9.6 (2B4), U9.38 (1B12)
/Memory/DataB4: U8.16 (Q4), U9.8 (2B5), U9.36 (1B13)
/Memory/DataB5: U8.17 (Q5), U9.9 (2B6), U9.35 (1B14)
/Memory/DataB6: U8.18 (Q6), U9.11 (2B7), U9.33 (1B15)
/Memory/DataB7: U8.19 (Q7), U9.12 (2B8), U9.32 (1B16)
/Memory/~BufSel: U4.3, U4.4, U5.29 (~OE2), U6.29 (~OE2), U7.22 (~OE), U9.29 (~OE2)
/Memory/~WeA: U4.6, U7.27 (~WE)
/Memory/~WeB: U4.11, U8.27 (~WE)
/Phi2: J1.1, U1.5
/Red: J7.1, J15.1, R6.2, R7.2, R8.2, R11.1
/R~W: J1.2, U3.4, U3.10
/VBlank: J13.1, U2.12, U3.2, U25.6 (Q)
/WriteMem: U3.8, U4.5, U4.13
/~FbSel: J5.2, U2.6, U3.5, U3.9
/~HSync: J7.13, J12.1, U16.9 (~Q)
/~NMI: J5.1, U2.11
/~Phi2: U1.6, U3.11, U29.11 (CP)
/~RegSel: U2.3, U3.3
/~VSync: J7.14, J14.1, U25.9 (~Q)
/~WriteReg: U1.11, U29.1 (~E)
GND: C1.2, C2.2, C3.2, C4.2, C5.2, C6.2, C7.2, C8.2, C9.2, C10.2, C11.2, C12.2, C13.2, C14.2, C15.2, C16.2, C17.2, C18.2, C19.2, C20.2, C21.2, C22.2, C23.2, C24.2, C25.2, C26.2, C27.2, C28.2, C29.2, C30.2, C31.2, C32.2, C33.2, C34.2, C35.2, J3.2, J7.5, J7.6, J7.7, J7.8, J7.10, R9.2, R10.2, R11.2, U1.7 (GND), U1.9, U1.10, U2.7 (GND), U2.9, U2.10, U3.7 (GND), U4.7 (GND), U4.9, U4.10, U5.13 (GND), U5.26 (2B16), U5.31 (A16), U5.32 (1B16), U5.44 (GND), U6.13 (GND), U6.26 (2B16), U6.31 (A16), U6.32 (1B16), U6.44 (GND), U7.14 (GND), U7.20 (~CS), U8.14 (GND), U8.20 (~CS), U9.13 (GND), U9.44 (GND), U10.7 (GND), U11.7 (GND), U12.7 (GND), U13.7 (GND), U14.3 (D0), U14.4 (D1), U14.5 (D2), U14.6 (D3), U14.8 (GND), U15.1, U15.3, U15.7 (GND), U16.8 (GND), U17.3 (D0), U17.4 (D1), U17.5 (D2), U17.6 (D3), U17.8 (GND), U18.7 (GND), U18.13, U19.4, U19.5, U19.7 (GND), U20.3 (D0), U20.4 (D1), U20.5 (D2), U20.6 (D3), U20.8 (GND), U21.7 (GND), U22.7 (GND), U23.7 (GND), U24.7 (GND), U25.8 (GND), U26.3 (D0), U26.4 (D1), U26.5 (D2), U26.6 (D3), U26.8 (GND), U27.3 (D0), U27.4 (D1), U27.5 (D2), U27.6 (D3), U27.8 (GND), U28.3 (D0), U28.4 (D1), U28.5 (D2), U28.6 (D3), U28.8 (GND), U29.10 (GND), U29.14 (D5), U29.17 (D6), U29.18 (D7), U30.7 (GND), U31.7 (GND), U32.7 (GND), U33.7 (GND), X1.4 (GND)
unnamed: R1.1, U32.6
unnamed: R2.1, U32.8
unnamed: R3.1, U32.11
unnamed: R4.1, U32.3
unnamed: R5.1, U33.6
unnamed: R6.1, U33.8
unnamed: R7.1, U33.11
unnamed: R8.1, U33.3
unnamed: U1.3, U2.4
unnamed: U1.13, U3.6
unnamed: U12.8, U15.9
unnamed: U14.15 (TC), U17.7 (CEP), U20.7 (CEP)
unnamed: U17.15 (TC), U20.10 (CET)
unnamed: U18.9, U23.8
unnamed: U18.11, U21.8
unnamed: U19.3, U21.12
unnamed: U19.8, U23.12
unnamed: U19.11, U23.11
unnamed: U26.15 (TC), U27.7 (CEP), U28.7 (CEP)
unnamed: U27.15 (TC), U28.10 (CET)
unnamed: U30.3, U32.12
unnamed: U30.6, U32.9
unnamed: U30.8, U32.4
unnamed: U30.11, U32.1
unnamed: U31.3, U33.12
unnamed: U31.6, U33.9
unnamed: U31.8, U33.4
unnamed: U31.11, U33.1

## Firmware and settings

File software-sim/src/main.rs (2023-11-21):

mod cpu;

use std::{thread, sync::{mpsc::{channel, Receiver, Sender}, Mutex, Arc}, time::Duration, process::exit};

use cpu::{CpuContext, create_arch, Cpu};

use minifb::{Window, WindowOptions, Scale};

use bitfield::bitfield;

bitfield! {
    pub struct FbConfig(u8);
    impl Debug;

    pub buf_sel, set_buf_sel: 0;
    pub bank_sel, set_bank_sel: 1;
    pub nmi_enable, set_nmi_enable: 2;
    pub blank_white, set_blank_white: 3;
    pub blank_black, set_blank_black: 4;
    pub _reserved, _: 7, 5;
}

pub struct Ctx {
    pub ram: [u8; 0x8000], // 32k
    pub eeprom: [u8; 0x2000], // 8k

    // Framebuffer
    pub vram: [u8; 0x10000], // 64k
    pub fb_config: FbConfig,
}

impl Ctx {
    fn new(eeprom: [u8; 0x2000]) -> Ctx {
        Ctx {
            ram: [0u8; 0x8000],
            eeprom,
            vram: [0u8; 0x10000],
            fb_config: FbConfig(0),
        }
    }

    fn get_bank(&self) -> usize {
        self.fb_config.bank_sel() as usize
    }

    fn get_buf(&self) -> usize {
        self.fb_config.buf_sel() as usize
    }

    fn get_nmienable(&self) -> bool {
        self.fb_config.nmi_enable()
    }

    fn get_blank_black(&self) -> bool {
        self.fb_config.blank_black()
    }

    fn get_blank_white(&self) -> bool {
        self.fb_config.blank_white()
    }

    fn get_vram_address(&self, addr: u16) -> usize {
        (self.get_buf() << 15) | (self.get_bank() << 14) | ((addr & 0x3FFF) as usize)
    }
}

impl CpuContext for Ctx {
    fn read_immut(&self, addr: u16) -> u8 {
        match addr {
            0x0000 ..= 0x7FFF => self.ram[addr as usize],
            // Vram is write-only
            0xE000 ..= 0xFFFF => self.eeprom[(addr-0xE000) as usize],
            _ => 0x00
        }
    }

    fn read(&mut self, addr: u16) -> u8 { self.read_immut(addr) }

    fn write(&mut self, addr: u16, val: u8) {
        // println!("write: ${addr:04x} <- ${val:02x}");
        if addr == 0x80a0 {
            self.fb_config.0 = val;
            println!("wrote to fb config: {:8b} {:?}", self.fb_config.0, self.fb_config);
        }
        match addr {
            0x0000..=0x7FFF => self.ram[addr as usize] = val,
            0x8000..=0xBFFF => self.vram[self.get_vram_address(addr)] = val,
            // EEPROM is read-only
            _ => ()
        }
    }
}

impl Default for Ctx {
    fn default() -> Self {
        Ctx::new([0xEAu8; 0x2000])
    }
}

fn run_fb(ctx: Arc<Mutex<Ctx>>, tx_nmi: Sender<()>) -> Receiver<()> {
    let mut window = Window::new(
        "6502 Framebuffer Emulator",
        256, 256,
        WindowOptions {
            scale: Scale::X4,
            ..Default::default()
        }
    ).expect("Could not create window");
    
    println!("Created window");
    while window.is_open() {
        let ctx = ctx.lock().unwrap();
        // println!("frame");
        if ctx.get_blank_black() {
            window.update_with_buffer(&[0u32; 256*256], 256, 256).unwrap();
        }
        else if ctx.get_blank_white() {
            window.update_with_buffer(&[0x00FFFFFFu32; 256*256], 256, 256).unwrap();
        }
        else {
            window.update_with_buffer(
                &ctx.vram.map(|x| {
                    let x = x as u32;
                    ((x & 0b11100000) << 16) |
                    ((x & 0b00011100) << (8 + 3)) |
                    ((x & 0b00000011) << 6)
                }),
                256,
                256
            ).unwrap();
        }
        let nmi = ctx.get_nmienable();
        drop(ctx);
        thread::sleep(Duration::from_micros(15253));
        if nmi {tx_nmi.send(()).unwrap();}
        thread::sleep(Duration::from_micros(1400));
    }

    println!("FB thread shutting down");
    exit(0);
}

fn create_cpu_thread(ctx: Arc<Mutex<Ctx>>, rx_nmi: Receiver<()>) {
    thread::spawn(move || {
        // eeprom[0x1FF0] = 0x4C;
        let arch = create_arch::<Ctx>();

        let mut cpu = Cpu::new();

        // let mut cycle = 0u32;
        loop {
            let mut ctx = ctx.lock().unwrap();
            cpu.next(&mut *ctx, &arch);
            if rx_nmi.try_recv().is_ok() {
                cpu.trigger_nmi(&mut *ctx);
                // println!("NMI!");
            }
            drop(ctx);

            // if cycle % 1000 == 0 {println!("cycle");}
            thread::sleep(Duration::from_micros(1));
            // println!("cycle {cycle}");
            // cycle += 1;
        }
    });
}

fn main() {
    let prog = std::fs::read(std::env::args().nth(1).unwrap()).unwrap();
    let mut eeprom = [0u8; 0x2000];
    eeprom.copy_from_slice(&prog[2..]);
    let ctx = Arc::new(Mutex::new(Ctx::new(eeprom)));

    let (tx_nmi, rx_nmi) = channel::<()>();

    create_cpu_thread(ctx.clone(), rx_nmi);

    run_fb(ctx, tx_nmi);
}

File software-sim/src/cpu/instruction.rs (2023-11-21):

#![allow(non_snake_case)]
#![allow(unused)]

use super::Cpu;
use super::CpuContext;
use std::cmp::Ordering;
use std::num::Wrapping;
use std::str::FromStr;

pub type Arch<'a, Ctx> = [Option<Instruction<'a, Ctx>>; 256];

#[derive(Debug, Clone, Copy, PartialEq, Eq)]
pub enum AddressingMode {
    Impl,
    Imm,
    Rel,
    Zpg,
    ZpgX,
    ZpgY,
    XInd,
    IndY,
    Ind,
    Abs,
    AbsX,
    AbsY,
}

pub enum Address {
    Implied,
    Immediate(u8),
    Addressed(u16),
}

impl AddressingMode {
    pub fn size(self) -> usize {
        match self {
            AddressingMode::Impl => 1,
            AddressingMode::Imm => 2,
            AddressingMode::Zpg => 2,
            AddressingMode::ZpgX => 2,
            AddressingMode::ZpgY => 2,
            AddressingMode::XInd => 2,
            AddressingMode::Ind => 3,
            AddressingMode::IndY => 2,
            AddressingMode::Rel => 2,
            AddressingMode::Abs => 3,
            AddressingMode::AbsX => 3,
            AddressingMode::AbsY => 3,
        }
    }

    pub fn address<Ctx: CpuContext>(self, ctx: &mut Ctx, cpu: &Cpu) -> (Address, usize) {
        match self {
            AddressingMode::Impl => (Address::Implied, 0),
            AddressingMode::Imm => (Address::Immediate(cpu.read(cpu.pc + 1, ctx)), 0),
            AddressingMode::Zpg => (Address::Addressed(cpu.read(cpu.pc + 1, ctx) as u16), 0),
            AddressingMode::ZpgX => (
                Address::Addressed(cpu.read(cpu.pc + 1, ctx).wrapping_add(cpu.x) as u16),
                0,
            ),
            AddressingMode::ZpgY => (
                Address::Addressed(cpu.read(cpu.pc + 1, ctx).wrapping_add(cpu.y) as u16),
                0,
            ),
            AddressingMode::Ind => (Address::Addressed(cpu.read_wide(cpu.pc + 1, ctx)), 0),
            AddressingMode::XInd => {
                let zpg_addr = cpu.read(cpu.pc + 1, ctx);
                (
                    Address::Addressed(cpu.read_wide(zpg_addr.wrapping_add(cpu.x) as u16, ctx)),
                    0,
                )
            }
            AddressingMode::Rel => (Address::Immediate(cpu.read(cpu.pc + 1, ctx)), 0),
            AddressingMode::IndY => {
                let zpg_addr = cpu.read(cpu.pc + 1, ctx);
                let mut effective_addr = cpu.read_wide(zpg_addr as u16, ctx);
                let prev = effective_addr;
                effective_addr = effective_addr.wrapping_add(cpu.y as u16);
                let cycles = if prev >> 8 != effective_addr >> 8 {
                    1
                } else {
                    0
                };
                (Address::Addressed(effective_addr), cycles)
            }
            AddressingMode::Abs => (Address::Addressed(cpu.read_wide_nowrap(cpu.pc + 1, ctx)), 0),
            AddressingMode::AbsX => {
                let addr = cpu.read_wide_nowrap(cpu.pc + 1, ctx);
                let eff_addr = addr.wrapping_add(cpu.x as u16);
                let cycles = if addr >> 8 != eff_addr >> 8 { 1 } else { 0 };
                (Address::Addressed(eff_addr), cycles)
            }
            AddressingMode::AbsY => {
                let addr = cpu.read_wide_nowrap(cpu.pc + 1, ctx);
                let eff_addr = addr.wrapping_add(cpu.y as u16);
                let cycles = if addr >> 8 != eff_addr >> 8 { 1 } else { 0 };
                (Address::Addressed(eff_addr), cycles)
            }
        }
    }
}

impl FromStr for AddressingMode {
    type Err = String;

    fn from_str(s: &str) -> Result<AddressingMode, String> {
        match s {
            "" => Ok(AddressingMode::Impl),
            "imm" => Ok(AddressingMode::Imm),
            "zpg" => Ok(AddressingMode::Zpg),
            "zpg,X" => Ok(AddressingMode::ZpgX),
            "zpg,Y" => Ok(AddressingMode::ZpgY),
            "ind" => Ok(AddressingMode::Ind),
            "X,ind" => Ok(AddressingMode::XInd),
            "ind,Y" => Ok(AddressingMode::IndY),
            "abs" => Ok(AddressingMode::Abs),
            "abs,X" => Ok(AddressingMode::AbsX),
            "abs,Y" => Ok(AddressingMode::AbsY),
            "rel" => Ok(AddressingMode::Rel),
            _ => Err(s.to_string()),
        }
    }
}

enum Operation<'a, Ctx> {
    Addressed(&'a (dyn Fn(&mut Ctx, &mut Cpu, u16) + Sync)),
    Immediate(&'a (dyn Fn(&mut Ctx, &mut Cpu, u8) + Sync)),
    Implied(&'a (dyn Fn(&mut Ctx, &mut Cpu) + Sync)),
}

impl<'a, Ctx: CpuContext> Operation<'a, Ctx> {
    pub fn run(&self, ctx: &mut Ctx, cpu: &mut Cpu, addr: &Address) {
        match self {
            Operation::Addressed(f) => {
                if let Address::Addressed(a) = addr {
                    f(ctx, cpu, *a)
                } else {
                    panic!()
                }
            }
            Operation::Immediate(f) => {
                if let Address::Immediate(a) = addr {
                    f(ctx, cpu, *a)
                } else {
                    panic!()
                }
            }
            Operation::Implied(f) => {
                if let Address::Implied = addr {
                    f(ctx, cpu)
                } else {
                    panic!()
                }
            }
        }
    }
}

pub struct Instruction<'a, Ctx> {
    pub opcode: String,
    pub mode: AddressingMode,
    pub cycles: u8,
    operation: Operation<'a, Ctx>,
}

impl<'a, Ctx: CpuContext> Instruction<'a, Ctx> {
    pub fn run(&self, ctx: &mut Ctx, cpu: &mut Cpu) -> usize {
        let last_pc = cpu.pc;

        let (addr, addr_cycles) = self.mode.address(ctx, cpu);

        self.operation.run(ctx, cpu, &addr);

        let mut cycles = self.cycles as usize;

        if !self.opcode.starts_with("STA") {
            cycles += addr_cycles;
        }

        // Check for page boundary crossings
        // if this is a branch instruction
        if self.mode == AddressingMode::Rel {
            let unbranched = last_pc + self.mode.size() as u16;
            let taken = last_pc != cpu.pc;

            if taken {
                cycles += 1;

                if unbranched >> 8 != (cpu.pc + self.mode.size() as u16) >> 8 {
                    cycles += 1;
                }
            }
        }

        cpu.pc = cpu.pc.checked_add(self.mode.size() as u16)
            .expect("PC overflow");

        cycles
    }
}
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

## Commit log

2023-10-18 initial commit (~2 weeks of work)
    [6502gpu.kicad_pcb, 6502gpu.kicad_sch, config_reg.kicad_sch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]
2023-10-23 remove 3390, cleanup
    [6502gpu.kicad_sch, config_reg.kicad_sch, counters.kicad_sch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]
2023-10-29 work on DAC
    [6502gpu.kicad_sch, config_reg.kicad_sch, dac.kicad_sch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]
2023-10-29 work on main page layout
    [6502gpu.kicad_sch, config_reg.kicad_sch, dac.kicad_sch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]
2023-10-29 finish control logic?
    [6502gpu.kicad_sch]
2023-11-02 misc fixes, start on pcb
    [6502gpu.kicad_pcb, 6502gpu.kicad_sch, config_reg.kicad_sch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]
2023-11-02 fix and update verilog model
    [6502gpu.kicad_sch, power.kicad_sch]
2023-11-04 more component-level simulation
    [6502gpu.kicad_sch, power.kicad_sch]
2023-11-04 Fix some timing, simulate writing to memory
    [6502gpu.kicad_sch, power.kicad_sch]
2023-11-05 Work on layout/routing
    [6502gpu.kicad_pcb, dac.kicad_sch, power.kicad_sch]
2023-11-05 More routing work
    [6502gpu.kicad_pcb]
2023-11-07 pcb organization
    [6502gpu.kicad_pcb, 6502gpu.kicad_sch, counters.kicad_sch]
2023-11-07 Suuuper dense routing for column counter
    [6502gpu.kicad_pcb, counters.kicad_sch, power.kicad_sch]
2023-11-07 Row counter logic
    [6502gpu.kicad_pcb, counters.kicad_sch]
2023-11-08 Routing work
    [6502gpu.kicad_pcb, 6502gpu.kicad_sch, counters.kicad_sch]
2023-11-08 Memory routing *screams*
    [6502gpu.kicad_pcb, counters.kicad_sch, memory.kicad_sch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]
2023-11-08 MOOORE memory routing
    [6502gpu.kicad_pcb, memory.kicad_sch]
2023-11-09 more layout
    [6502gpu.kicad_pcb]
2023-11-10 layout continues...
    [6502gpu.kicad_pcb, 6502gpu.kicad_sch, config_reg.kicad_sch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]
2023-11-11 finalize board layout at 140x110mm
    [6502gpu.kicad_pcb, 6502gpu.kicad_sch]
2023-11-11 almost done wiring...
    [6502gpu.kicad_pcb, 6502gpu.kicad_sch]
2023-11-12 Done routing!!
    [6502gpu.kicad_pcb, 6502gpu.kicad_sch, config_reg.kicad_sch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]
2023-11-13 Make DRC quiet, add loooots of vias
    [6502gpu.kicad_pcb, counters.kicad_sch, power.kicad_sch]
2023-11-13 Test exporting
    [6502gpu.kicad_pcb]
2023-11-18 fix colors for rendering
    [main.rs]
2023-11-18 Run event loop on main thread to prevent crash
    [main.rs]
2023-12-05 begin rev 2... more routing :(
    [6502fb.kicad_sch, config_reg.kicad_sch, memory.kicad_sch]
2023-12-05 fix HC377 package
    [config_reg.kicad_sch, memory.kicad_sch]
2023-12-19 Rev2 work
    [6502fb.kicad_sch, config_reg.kicad_sch, memory.kicad_sch]
2023-12-19 rev2 mostly done now
    [6502fb.kicad_sch, config_reg.kicad_sch, counters.kicad_sch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]
2023-12-20 fix VGA plug footprint
2024-01-07 add caps for 7805
    [power.kicad_sch]
2024-01-07 rev 2 final version gerbers
